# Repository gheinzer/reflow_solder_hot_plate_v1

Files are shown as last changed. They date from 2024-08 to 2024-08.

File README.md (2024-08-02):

# Reflow Soldering Hot Plate (v1)
⚠️ This is not finished yet, I've just ordered the parts and I'm now waiting for them to arrive.

## About this project
I have a pretty bad soldering iron at home (it was very cheap and I once bought it in a local store). After trying (and failing) to solder small SMD components to a PCB, I wanted
to find some other solution to this problem.

So I looked at https://github.com/AfterEarthLTD/Solder-Reflow-Plate/ and https://github.com/DerSpatz/PCB-reflow-solder-heat-plate. These projects seem great to me, but they have one downside:
The actual usable, heated area seems to be quite small. And with that, the idea for this project was born.

## Note
I'm an electrical engineering apprentice, so I'm happy to learn about the mistakes I made when designing this :).

## Features
- ❇️ Separate hot plate and driver PCBs
- 🤏 Maximum PCB size: 100.0x100.0 mm (so it's cheap to order from JLCPCB)
- ♨️ Useable heated area for a rectangular PCB: ca. 84.0x73.0 mm
  - I know this is not that great, but the heater PCB can be swapped out independently of the driver. 
- 🔌 24V power supply input
- 📏 4-wire-voltage measurement for the heating element (used to calculate the temperature)
- ⚡ Current measurement and -regulation for variable-speed temperature transitions
- 📟 Built-in LCD display with adjustable contrast
- ↕️ 3 Buttons for navigation
- ⏱️ Theoretically fast heat-up-times (~4A max. heating current)

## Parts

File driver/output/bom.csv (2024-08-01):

Reference | Value | Datasheet | Footprint | Qty | DNP
C1 | 100n | ~ | Capacitor_SMD:C_0805_2012Metric_Pad1.18x1.45mm_HandSolder | 1
C2,C4,C6,C7,C8,C9,C10,C12,C14,C17 | 10n | ~ | Capacitor_SMD:C_0805_2012Metric_Pad1.18x1.45mm_HandSolder | 10
C3,C5,C11,C13,C15 | 10u | ~ | Capacitor_SMD:C_0805_2012Metric_Pad1.18x1.45mm_HandSolder | 5
D1 | 1N4148 | https://assets.nexperia.com/documents/data-sheet/1N4148_1N4448.pdf | Diode_THT:D_DO-35_SOD27_P7.62mm_Horizontal | 1
J1 | ED550/4DS | ~ | Custom_TerminalBlock_OnShore:TerminalBlock_OnShore_ED550_4DS | 1
J2 | PJ-051AH | ~ | Connector_BarrelJack:BarrelJack_CUI_PJ-079BH_Horizontal | 1
J3 | TC2050 | ~ | Connector:Tag-Connect_TC2050-IDC-FP_2x05_P1.27mm_Vertical | 1
K1 | J107F1AS125VDC | ~ | Custom_Relay_THT:Relay_CIT_J107F1A | 1
Q1,Q2 | AOSS32334C | https://aosmd.com/res/data_sheets/AOSS32334C.pdf | Package_TO_SOT_SMD:SOT-23-3 | 2
R1,R8,R10,R11,R12,R13,R15 | 10k | ~ | Resistor_SMD:R_0805_2012Metric_Pad1.20x1.40mm_HandSolder | 7
R2 | Y14880R05000B0R | ~ | Custom_Resistor_SMD:R_Shunt_VFR_Y14880Rxxxxxxxx | 1
R3,R4 | 2k | ~ | Resistor_SMD:R_0805_2012Metric_Pad1.20x1.40mm_HandSolder | 2
R5,R6 | 160k | ~ | Resistor_SMD:R_0805_2012Metric_Pad1.20x1.40mm_HandSolder | 2
R7,R14 | 100k | ~ | Resistor_SMD:R_0805_2012Metric_Pad1.20x1.40mm_HandSolder | 2
R9,R16 | 15k | ~ | Resistor_SMD:R_0805_2012Metric_Pad1.20x1.40mm_HandSolder | 2
RV1 | 3386P-1-103LF | ~ | Potentiometer_THT:Potentiometer_Bourns_3386P_Vertical | 1
SW1,SW2,SW3 | B3S-1000 | ~ | Button_Switch_SMD:SW_SPST_B3S-1000 | 3
U1,U4 | OPA4196IDR | https://www.ti.com/general/docs/suppproductinfo.tsp?distId=10 | Package_SO:SOIC-14_3.9x8.7mm_P1.27mm | 2
U2 | LT323AT#PBF | https://mm.digikey.com/Volume0/opasdata/d220001/medias/docus/1103/LM323.pdf | Package_TO_SOT_THT:TO-220-3_Horizontal_TabDown | 1
U3 | ATtiny1634-S | http://ww1.microchip.com/downloads/en/DeviceDoc/Atmel-8303-8-bit-AVR-Microcontroller-tinyAVR-ATtiny1634_Datasheet.pdf | Package_SO:SOIC-20W_7.5x12.8mm_P1.27mm | 1
U5 | NHD-0420H1Z | http://www.newhavendisplay.com/specs/NHD-0420H1Z-FSW-GBW-33V3.pdf | Display:NHD-0420H1Z | 1
U6,U7 | MCP1700-3302E/TO | http://ww1.microchip.com/downloads/en/DeviceDoc/20001826D.pdf | Package_TO_SOT_THT:TO-92_Inline | 2

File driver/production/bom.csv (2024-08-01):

Designator | Footprint | Quantity | Value | LCSC Part #
C1 | 0805 | 1 | 100n
C10, C12, C14, C17, C2, C4, C6, C7, C8, C9 | 0805 | 10 | 10n
C11, C13, C15, C3, C5 | 0805 | 5 | 10u
D1 | D_DO-35_SOD27_P7.62mm_Horizontal | 1 | 1N4148
J1 | TerminalBlock_OnShore_ED550_4DS | 1 | ED550/4DS
J2 | BarrelJack_CUI_PJ-079BH_Horizontal | 1 | PJ-051AH
J3 | Tag-Connect_TC2050-IDC-FP_2x05_P1.27mm_Vertical | 1 | TC2050
K1 | Relay_CIT_J107F1A | 1 | J107F1AS125VDC
Q1, Q2 | SOT-23-3 | 2 | AOSS32334C
R1, R10, R11, R12, R13, R15, R8 | 0805 | 7 | 10k
R14, R7 | 0805 | 2 | 100k
R16, R9 | 0805 | 2 | 15k
R2 | R_Shunt_VFR_Y14880Rxxxxxxxx | 1 | Y14880R05000B0R
R3, R4 | 0805 | 2 | 2k
R5, R6 | 0805 | 2 | 160k
RV1 | Potentiometer_Bourns_3386P_Vertical | 1 | 3386P-1-103LF
SW1, SW2, SW3 | SW_SPST_B3S-1000 | 3 | B3S-1000
U1, U4 | SOIC-14_3.9x8.7mm_P1.27mm | 2 | OPA4196IDR
U2 | TO-220-3_Horizontal_TabDown | 1 | LT323AT#PBF
U3 | SOIC-20W_7.5x12.8mm_P1.27mm | 1 | ATtiny1634-S
U5 | NHD-0420H1Z | 1 | NHD-0420H1Z
U6, U7 | TO-92_Inline | 2 | MCP1700-3302E/TO

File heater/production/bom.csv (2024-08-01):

Designator | Footprint | Quantity | Value | LCSC Part #
J1 | TerminalBlock_OnShore_ED550_4DS | 1 | ED550/4DS

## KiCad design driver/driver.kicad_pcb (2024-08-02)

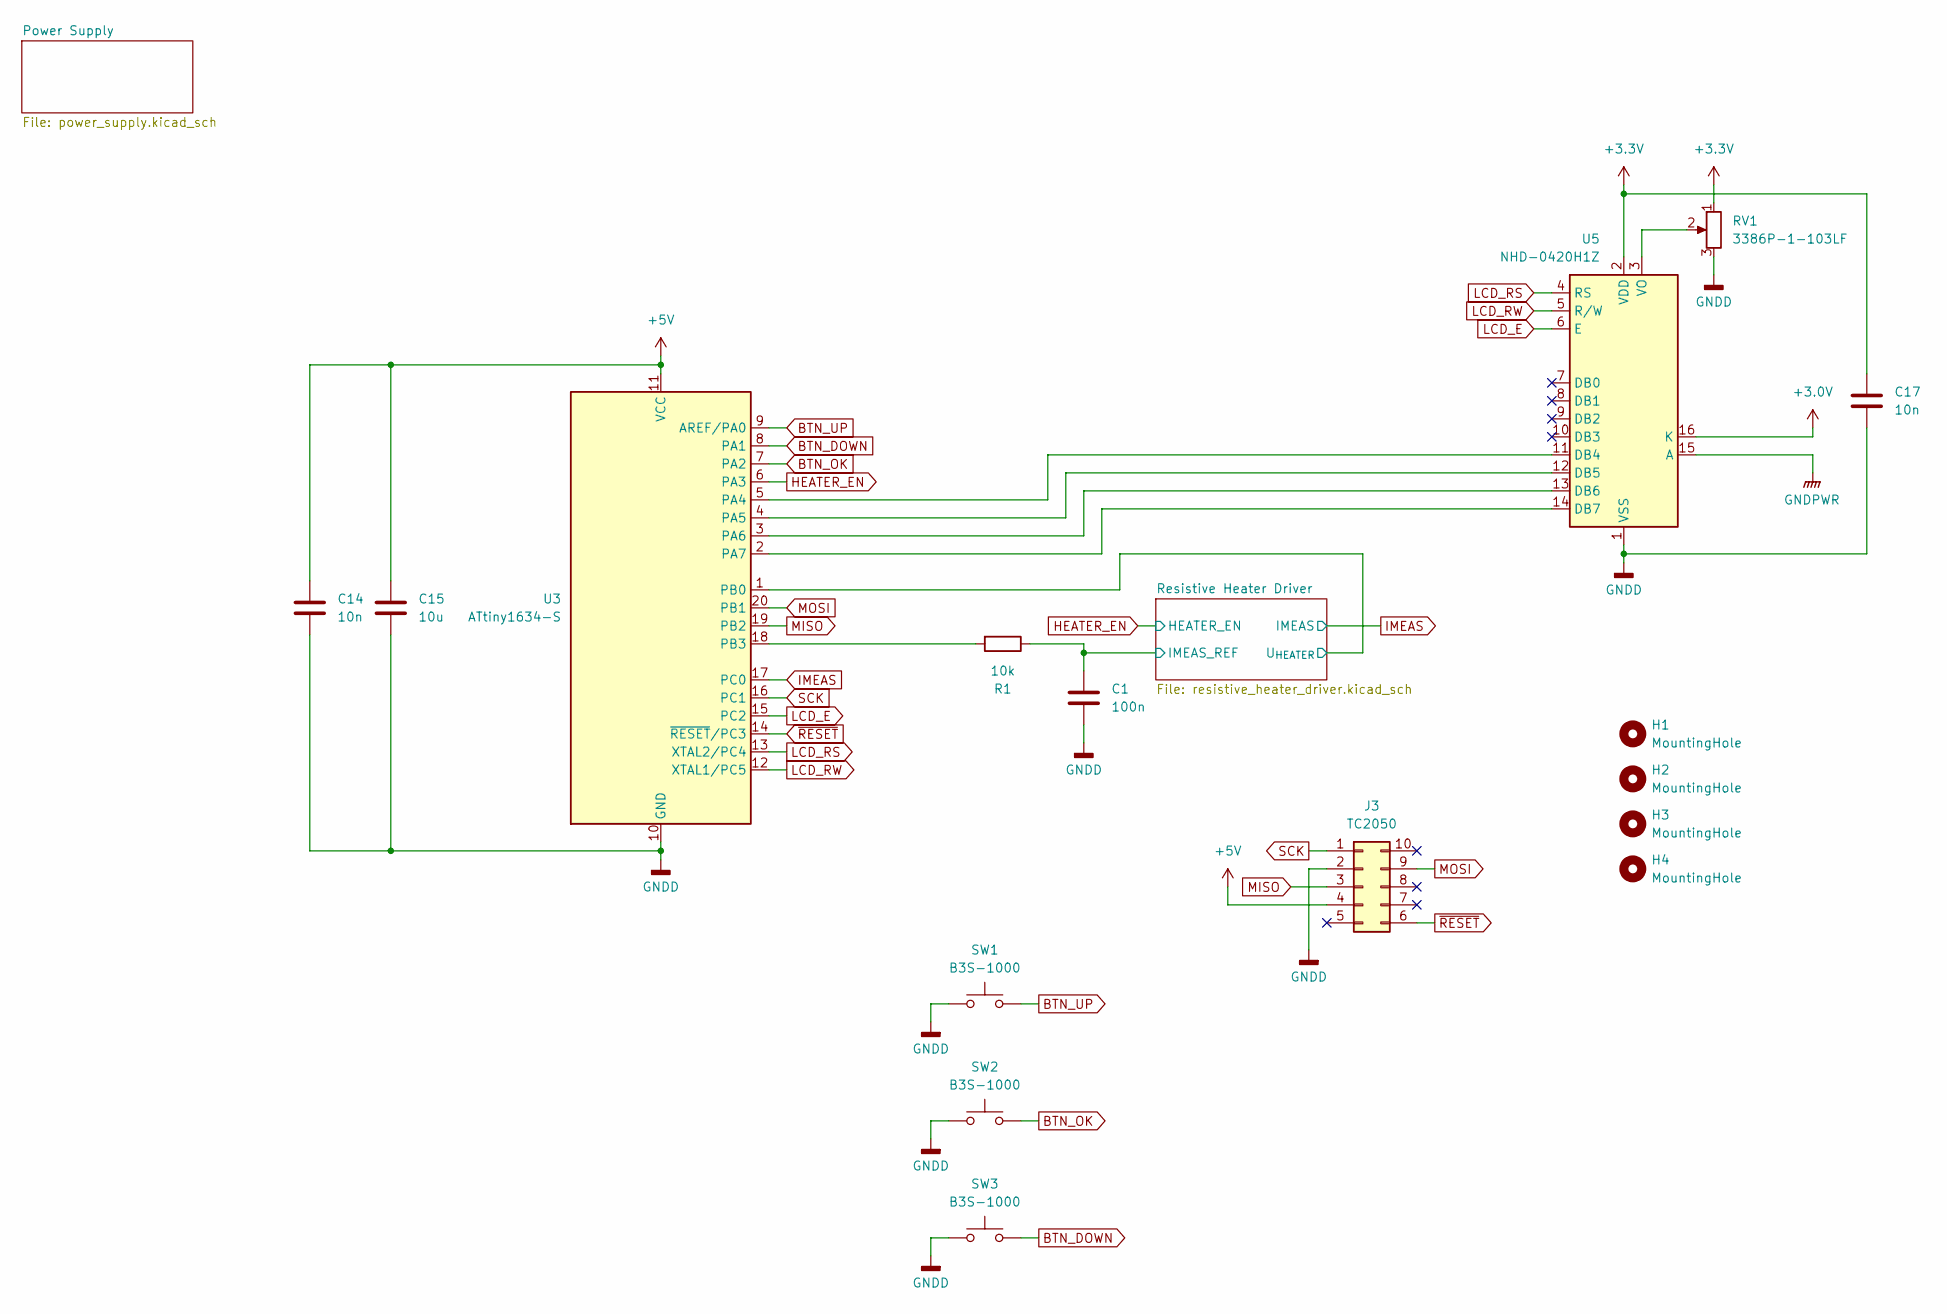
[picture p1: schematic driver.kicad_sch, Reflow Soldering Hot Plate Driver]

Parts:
C1: 100n; C_0805_2012Metric_Pad1.18x1.45mm_HandSolder
C14, C17: 10n; C_0805_2012Metric_Pad1.18x1.45mm_HandSolder
C15: 10u; C_0805_2012Metric_Pad1.18x1.45mm_HandSolder
H1, H2, H3, H4: MountingHole; MountingHole_3.2mm_M3
J3: TC2050; Tag-Connect_TC2050-IDC-FP_2x05_P1.27mm_Vertical
R1: 10k; R_0805_2012Metric_Pad1.20x1.40mm_HandSolder
RV1: 3386P-1-103LF; Potentiometer_Bourns_3386P_Vertical
SW1, SW2, SW3: B3S-1000; SW_SPST_B3S-1000
U3: ATtiny1634-S; SOIC-20W_7.5x12.8mm_P1.27mm
U5: NHD-0420H1Z

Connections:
+3.0V: U5.16 (K); also elsewhere on the board
+3.3V: C17.1, RV1.1, U5.2 (VDD); also elsewhere on the board
+5V: C14.1, C15.1, J3.4, U3.11 (VCC); also elsewhere on the board
/Resistive Heater Driver/IMEAS_REF: C1.1, R1.1; also elsewhere on the board
/Resistive Heater Driver/U_{HEATER}: U3.1 (PB0); also elsewhere on the board
BTN_DOWN: SW3.1, U3.8 (PA1)
BTN_OK: SW2.1, U3.7 (PA2)
BTN_UP: SW1.1, U3.9 (AREF/PA0)
GNDD: C1.2, C14.2, C15.2, C17.2, J3.2, RV1.3, SW1.2, SW2.2, SW3.2, U3.10 (GND), U5.1 (VSS); also elsewhere on the board
GNDPWR: U5.15 (A); also elsewhere on the board
HEATER_EN: U3.6 (PA3); also elsewhere on the board
IMEAS: U3.17 (PC0); also elsewhere on the board
LCD_E: U3.15 (PC2), U5.6 (E)
LCD_RS: U3.13 (XTAL2/PC4), U5.4 (RS)
LCD_RW: U3.12 (XTAL1/PC5), U5.5 (R/W)
MISO: J3.3, U3.19 (PB2)
MOSI: J3.9, U3.20 (PB1)
unnamed: U3.5 (PA4), U5.11 (DB4)
unnamed: U3.4 (PA5), U5.12 (DB5)
unnamed: U3.3 (PA6), U5.13 (DB6)
unnamed: U3.2 (PA7), U5.14 (DB7)
unnamed: R1.2, U3.18 (PB3)
unnamed: RV1.2, U5.3 (VO)
SCK: J3.1, U3.16 (PC1)
~RESET: J3.6, U3.14 (~RESET/PC3)

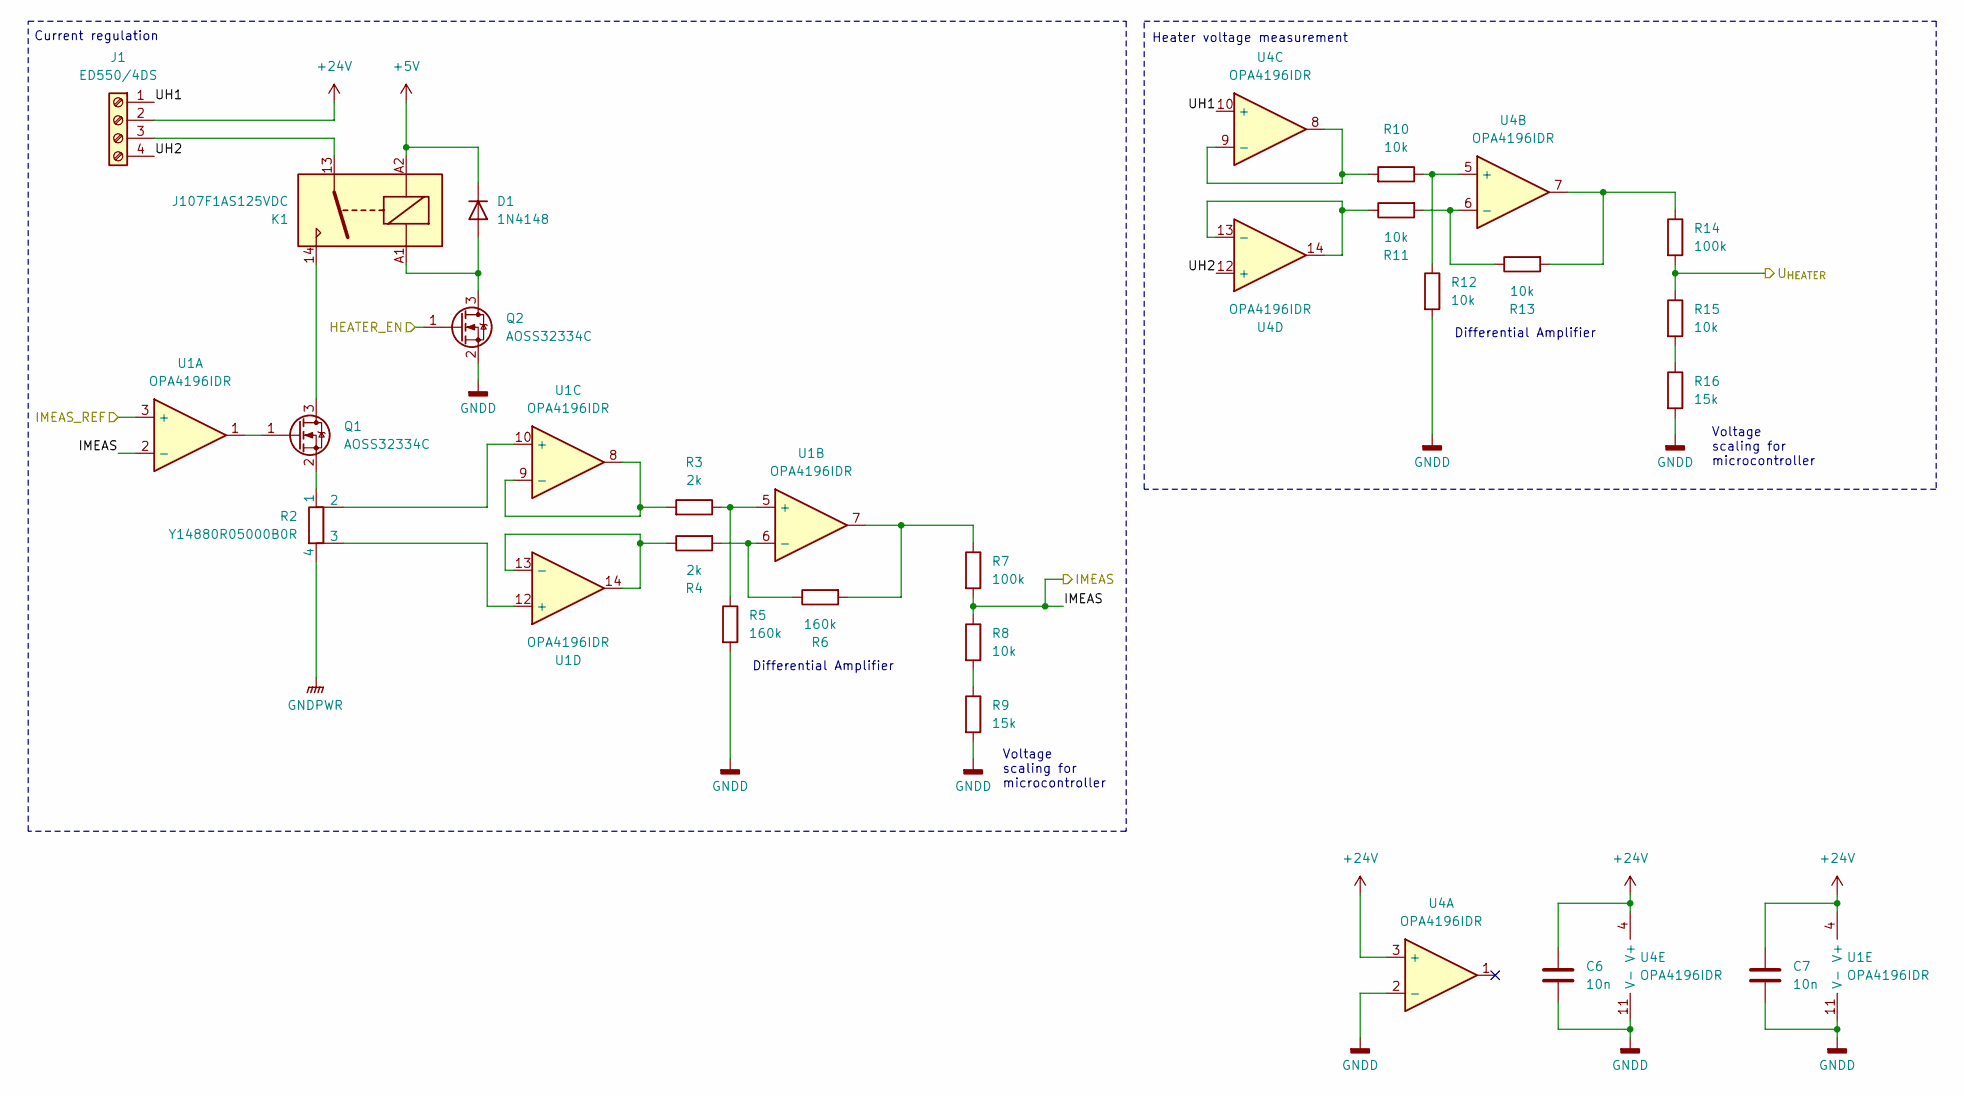
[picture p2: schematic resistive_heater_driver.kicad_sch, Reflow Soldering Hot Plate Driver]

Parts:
C6, C7: 10n; C_0805_2012Metric_Pad1.18x1.45mm_HandSolder
D1: 1N4148; D_DO-35_SOD27_P7.62mm_Horizontal
J1: ED550/4DS; TerminalBlock_OnShore_ED550_4DS
K1: J107F1AS125VDC; Relay_CIT_J107F1A
Q1, Q2: AOSS32334C; SOT-23-3
R2: Y14880R05000B0R; R_Shunt_VFR_Y14880Rxxxxxxxx
R3, R4: 2k; R_0805_2012Metric_Pad1.20x1.40mm_HandSolder
R5, R6: 160k; R_0805_2012Metric_Pad1.20x1.40mm_HandSolder
R7, R14: 100k; R_0805_2012Metric_Pad1.20x1.40mm_HandSolder
R8, R10, R11, R12, R13, R15: 10k; R_0805_2012Metric_Pad1.20x1.40mm_HandSolder
R9, R16: 15k; R_0805_2012Metric_Pad1.20x1.40mm_HandSolder
U1, U4: OPA4196IDR; SOIC-14_3.9x8.7mm_P1.27mm

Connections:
+5V: D1.1 (K), K1.A2; also elsewhere on the board
+24V: C6.1, C7.1, J1.2, U1.4 (V+), U4.3 (+), U4.4 (V+); also elsewhere on the board
/Resistive Heater Driver/IMEAS_REF: U1.3 (+); also elsewhere on the board
/Resistive Heater Driver/UH1: J1.1, U4.10 (+)
/Resistive Heater Driver/UH2: J1.4, U4.12 (+)
/Resistive Heater Driver/U_{HEATER}: R14.2, R15.1; also elsewhere on the board
GNDD: C6.2, C7.2, Q2.2 (S), R5.2, R9.2, R12.2, R16.2, U1.11 (V-), U4.2 (-), U4.11 (V-); also elsewhere on the board
GNDPWR: R2.4; also elsewhere on the board
HEATER_EN: Q2.1 (G); also elsewhere on the board
IMEAS: R7.2, R8.1, U1.2 (-); also elsewhere on the board
unnamed: D1.2 (A), K1.A1, Q2.3 (D)
unnamed: J1.3, K1.13
unnamed: K1.14, Q1.3 (D)
unnamed: Q1.1 (G), U1.1
unnamed: Q1.2 (S), R2.1
unnamed: R6.2, R7.1, U1.7
unnamed: R8.2, R9.1
unnamed: R13.2, R14.1, U4.7
unnamed: R15.2, R16.1
unnamed: R3.1, R5.1, U1.5 (+)
unnamed: R4.2, R6.1, U1.6 (-)
unnamed: R2.2, U1.10 (+)
unnamed: R3.2, U1.8, U1.9 (-)
unnamed: R2.3, U1.12 (+)
unnamed: R4.1, U1.13 (-), U1.14
unnamed: R10.1, R12.1, U4.5 (+)
unnamed: R11.2, R13.1, U4.6 (-)
unnamed: R10.2, U4.8, U4.9 (-)
unnamed: R11.1, U4.13 (-), U4.14

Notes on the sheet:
Differential Amplifier
Current regulation
Heater voltage measurement
Voltage scaling for microcontroller

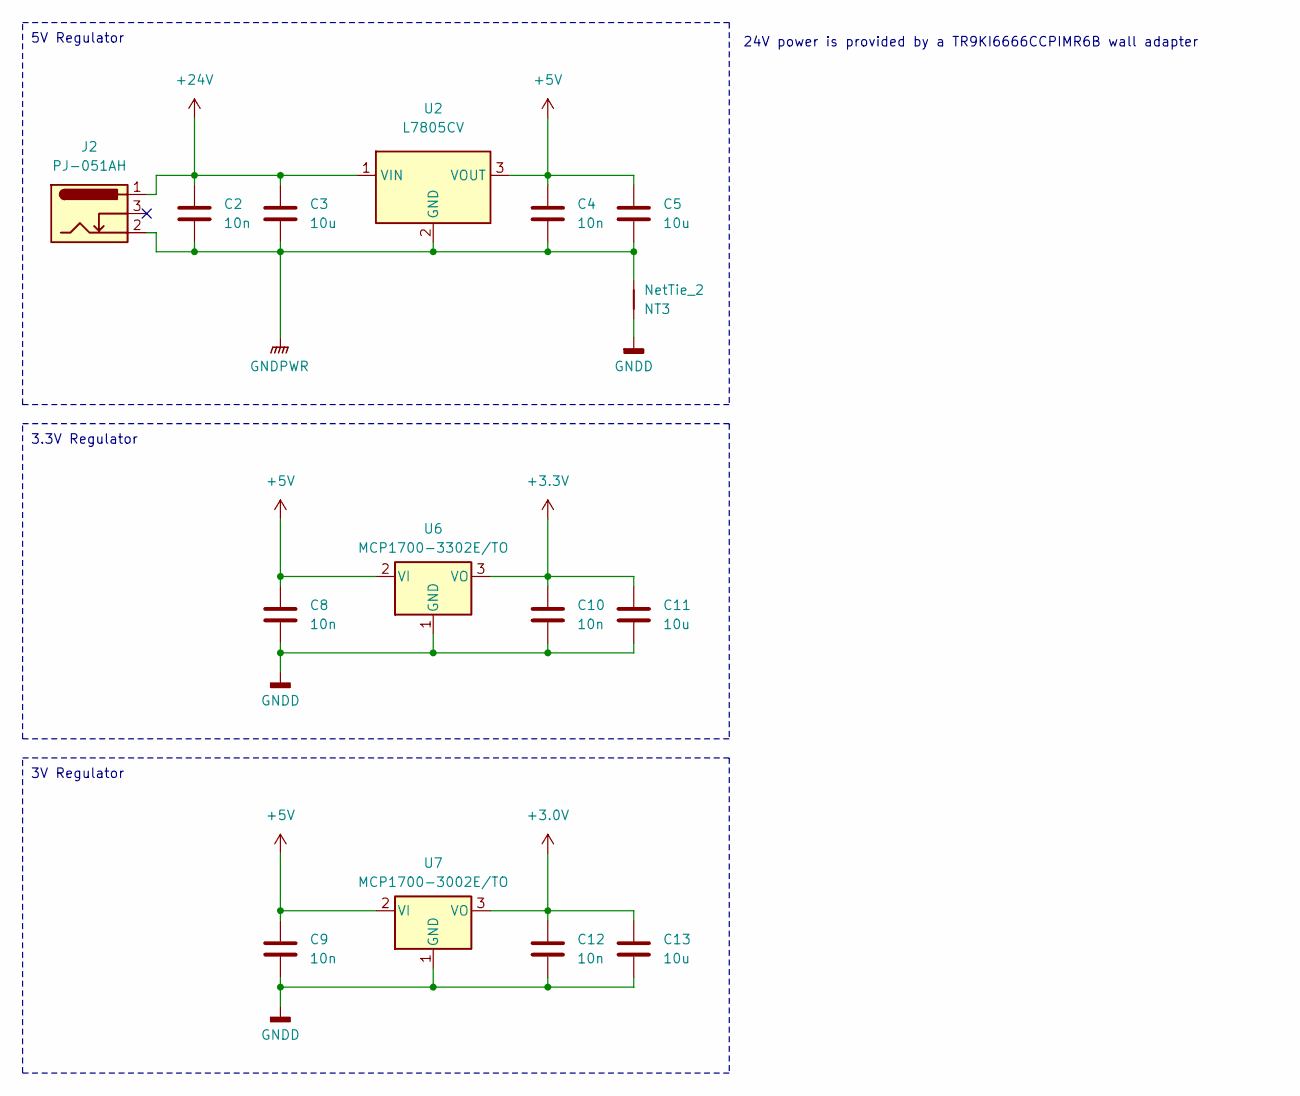
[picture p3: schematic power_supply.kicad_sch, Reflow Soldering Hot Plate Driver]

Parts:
C2, C4, C8, C9, C10, C12: 10n; C_0805_2012Metric_Pad1.18x1.45mm_HandSolder
C3, C5, C11, C13: 10u; C_0805_2012Metric_Pad1.18x1.45mm_HandSolder
J2: PJ-051AH; BarrelJack_CUI_PJ-079BH_Horizontal
NT3: NetTie_2; NetTie-2_THT_Pad1.0mm
U2: L7805CV; TO-220-3_Horizontal_TabDown
U6: MCP1700-3302E/TO; TO-92_Inline
U7: MCP1700-3002E/TO; TO-92_Inline

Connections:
+3.0V: C12.1, C13.1, U7.3 (VO); also elsewhere on the board
+3.3V: C10.1, C11.1, U6.3 (VO); also elsewhere on the board
+5V: C4.1, C5.1, C8.1, C9.1, U2.3 (VOUT), U6.2 (VI), U7.2 (VI); also elsewhere on the board
+24V: C2.1, C3.1, J2.1, U2.1 (VIN); also elsewhere on the board
GNDD: C8.2, C9.2, C10.2, C11.2, C12.2, C13.2, NT3.2, U6.1 (GND), U7.1 (GND); also elsewhere on the board
GNDPWR: C2.2, C3.2, C4.2, C5.2, J2.2, NT3.1, U2.2 (GND); also elsewhere on the board

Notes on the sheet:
5V Regulator
3V Regulator
24V power is provided by a TR9KI6666CCPIMR6B wall adapter
3.3V Regulator

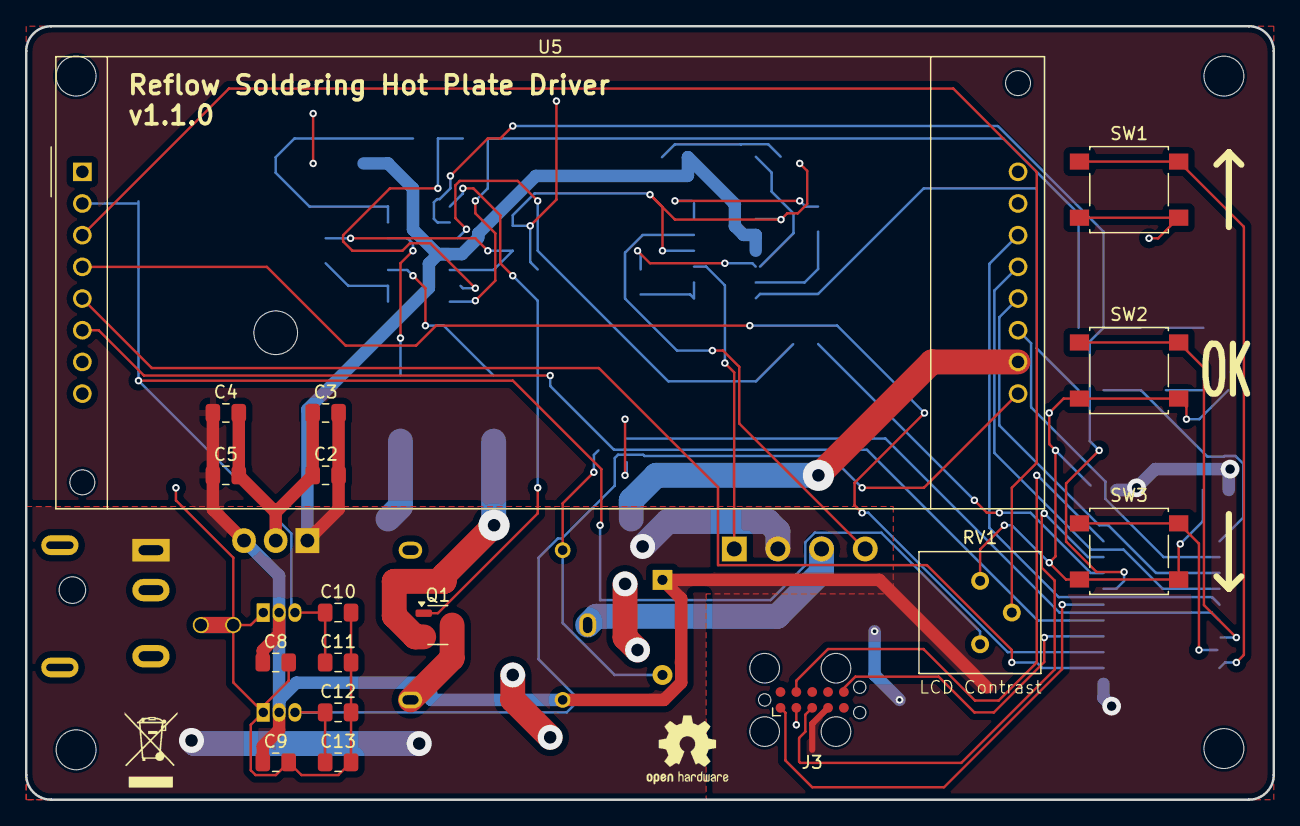
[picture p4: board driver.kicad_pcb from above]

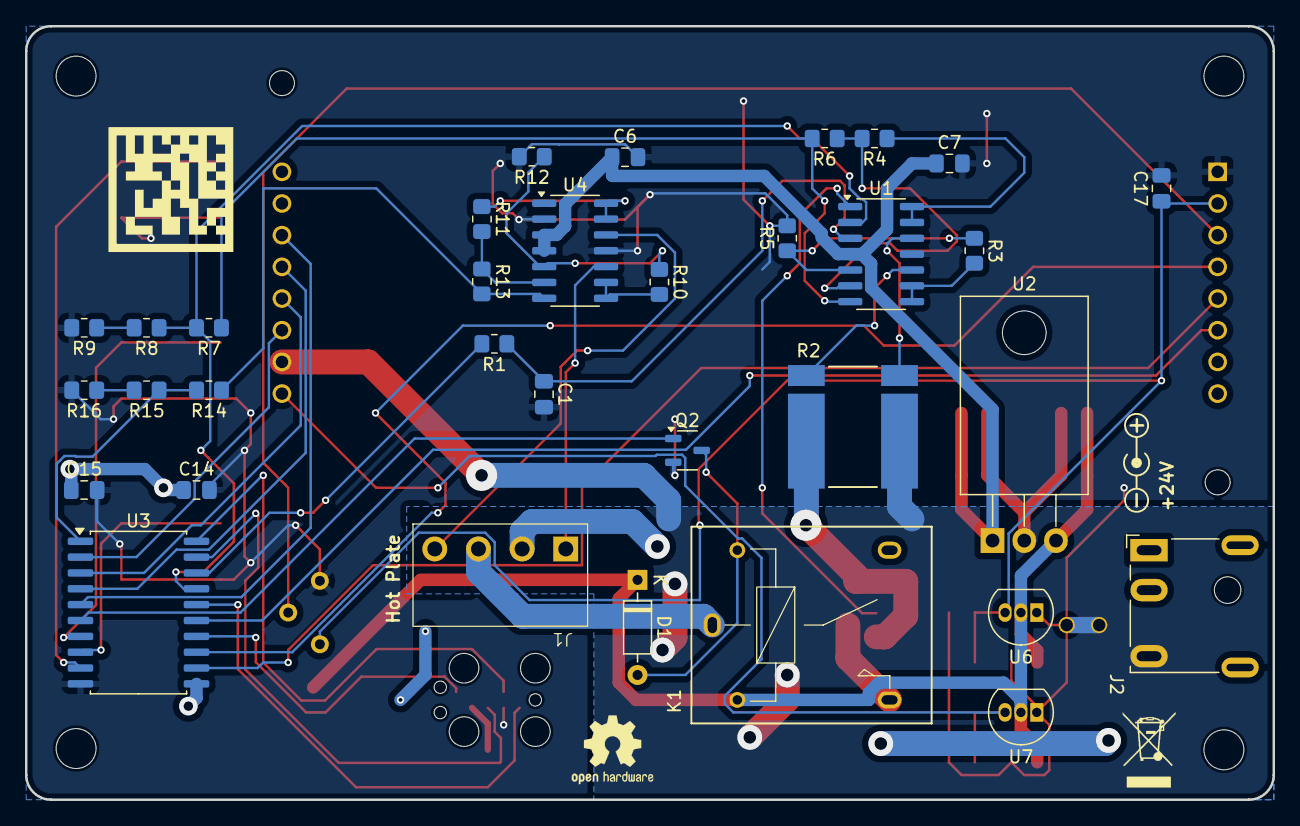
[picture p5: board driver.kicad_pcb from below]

Board: 2 copper layers, 100.0 x 62.0 mm, 55 parts (33 on the bottom side), 47 nets.

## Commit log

2024-08-01 Added existing project to git repository
    [bom.csv, designators.csv, driver (SFConflict 9453fa03dda942e3ac0a5e5975866dea@auth.local 2024-07-30-07-24-57).kicad_sch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]
2024-08-01 Added data matrix codes to PCBs for easy identification
    [driver.kicad_pcb, heater.kicad_pcb]
2024-08-02 Replaced 5V regulator with fully compatible alternative
    [driver.kicad_pcb, driver.kicad_sch, power_supply.kicad_sch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]
